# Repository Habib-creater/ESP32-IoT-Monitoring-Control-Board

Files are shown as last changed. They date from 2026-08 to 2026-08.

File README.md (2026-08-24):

# 4-Layer ESP32 IoT Monitoring and Control Board

<p align="center">
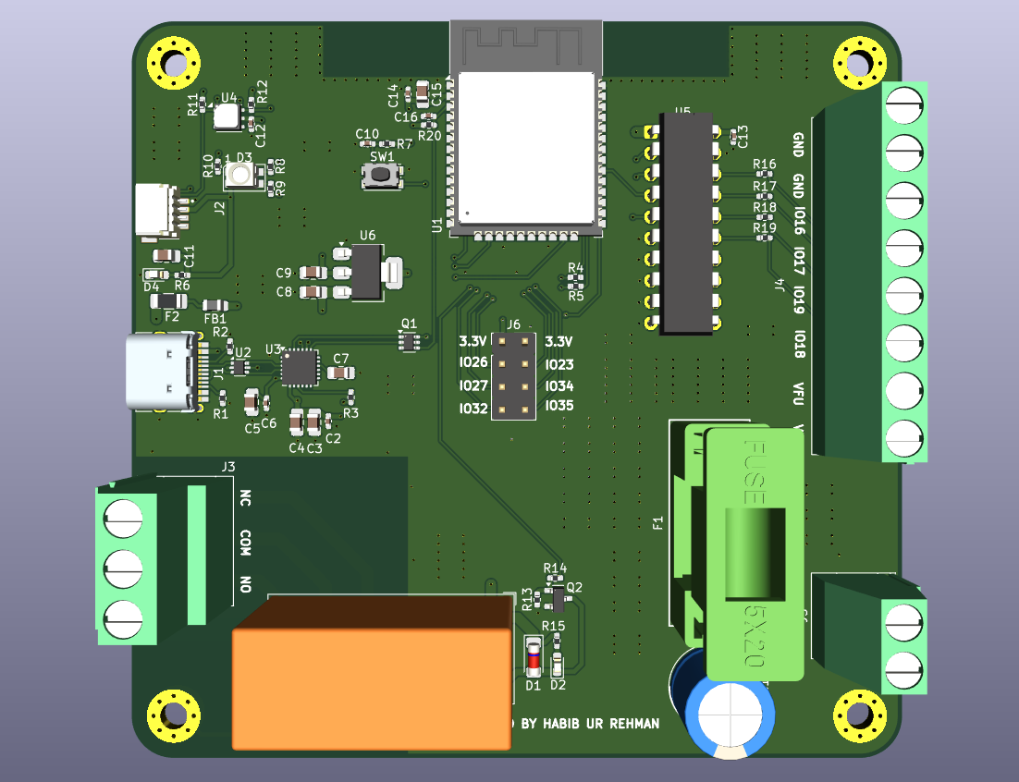
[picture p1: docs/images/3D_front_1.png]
4-Layer ESP32 IoT Monitoring and Control Board
  
</p>

<p align="center">
  <strong>ESP32-WROOM-32D • Si7021 • Relay • USB • Qwiic • 4-Layer PCB</strong>
</p>

<p align="center">
  A custom 4-layer ESP32-based hardware platform integrating environmental
  sensing, wired connectivity, relay control, USB programming, and
  expansion interfaces.
</p>

<p align="center">
  <a href="docs/IOT_Schematic.pdf">Schematic</a> •
  <a href="bom/IOT_BOM.csv">BOM</a> •
  <a href="manufacturing/gerbers/">Gerbers</a> •
  <a href="hardware/kicad/">KiCad Files</a>
</p>

---

## Overview

The **4-Layer ESP32 IoT Monitoring and Control Board** is a custom
embedded hardware platform built around the **ESP32-WROOM-32D** module.

The board combines environmental sensing through the **Si7021-A20**,
serial and wired interfaces, relay control, USB connectivity, Qwiic
expansion, and general-purpose GPIO in a compact 4-layer PCB design.

The complete hardware package is included in this repository, covering
the native **KiCad project**, electrical schematic, PCB layout, BOM,
Gerber and drill manufacturing files, pick-and-place data, and PCB
documentation.

> **Status:** Design files and manufacturing outputs included.

---

## Quick Access

| Resource | Description |
|---|---|
|  [Schematic PDF](docs/IOT_Schematic.pdf) | Complete electrical schematic |
|  [Bill of Materials](bom/IOT_BOM.csv) | Component BOM |
|  [Gerber & Drill Files](manufacturing/gerbers/) | PCB manufacturing outputs |
|  [KiCad Project](hardware/kicad/) | Native KiCad design files |
|  [PCB Images](docs/images/) | 3D renders and layer views |
|  [Pick-and-Place Data](manufacturing/pick-and-place/) | Component placement data |
|  [ERC / DRC Reports](docs/images/) | Design verification screenshots |

---

## Key Features

| Feature | Details |
|---|---|
| **Main Controller** | ESP32-WROOM-32D |
| **Environmental Sensor** | Si7021-A20 |
| **Sensor Interface** | I²C |
| **Serial / Expansion** | UART / GPIO |
| **Relay Control** | RT314A05 relay |
| **USB** | USB 2.0 Type-C interface |
| **Expansion** | Qwiic connector |
| **PCB** | 4-layer PCB |
| **EDA Software** | KiCad |
| **Manufacturing Data** | Gerber + PTH/NPTH drill files |
| **Assembly Data** | Top and bottom pick-and-place files |

---

## PCB Preview

### 3D Board Render

<p align="center">
  ESP32 IoT Board 3D Front Render
</p>

### Alternative 3D View

<p align="center">
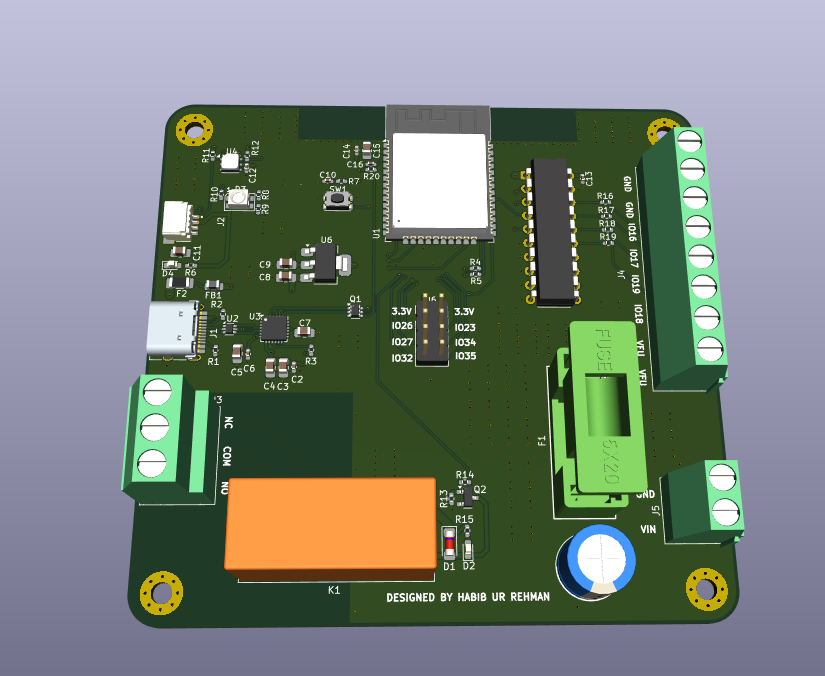
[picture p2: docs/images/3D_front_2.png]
ESP32 IoT Board Alternative 3D Render
  
</p>

### Bottom 3D View

<p align="center">
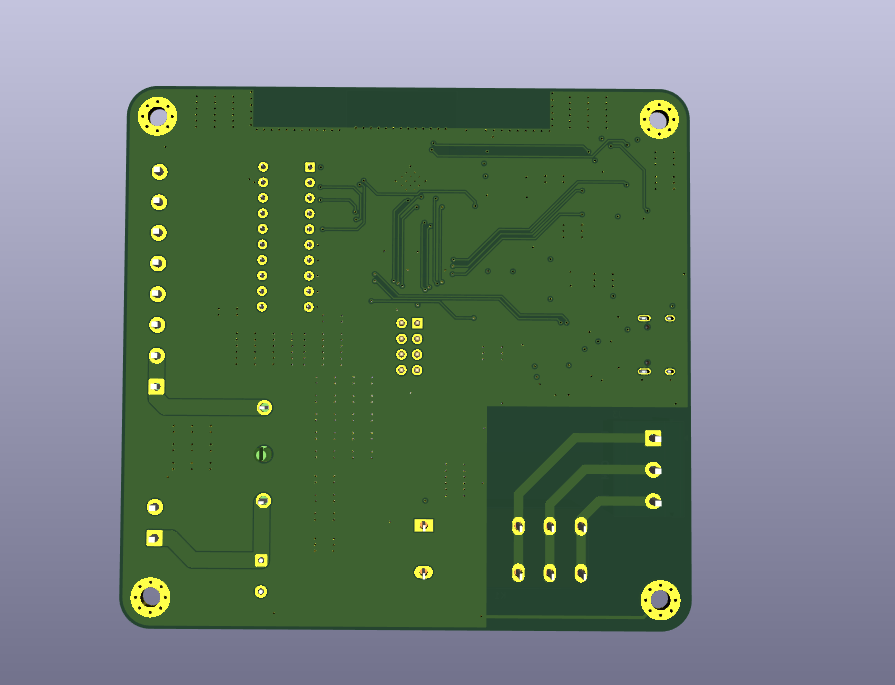
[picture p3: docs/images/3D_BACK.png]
ESP32 IoT Board Bottom 3D Render
  
</p>

---

## PCB Layer Views

### Front Copper / Layout

<p align="center">
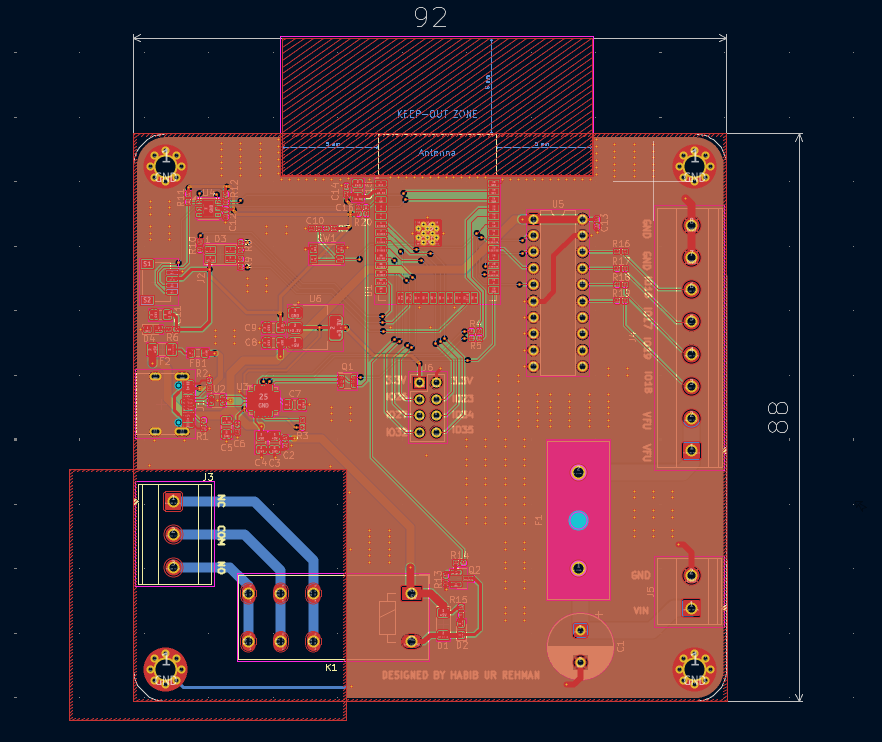
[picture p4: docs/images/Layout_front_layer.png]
ESP32 IoT PCB Front Layer
  
</p>

### Inner Layer 1

<p align="center">
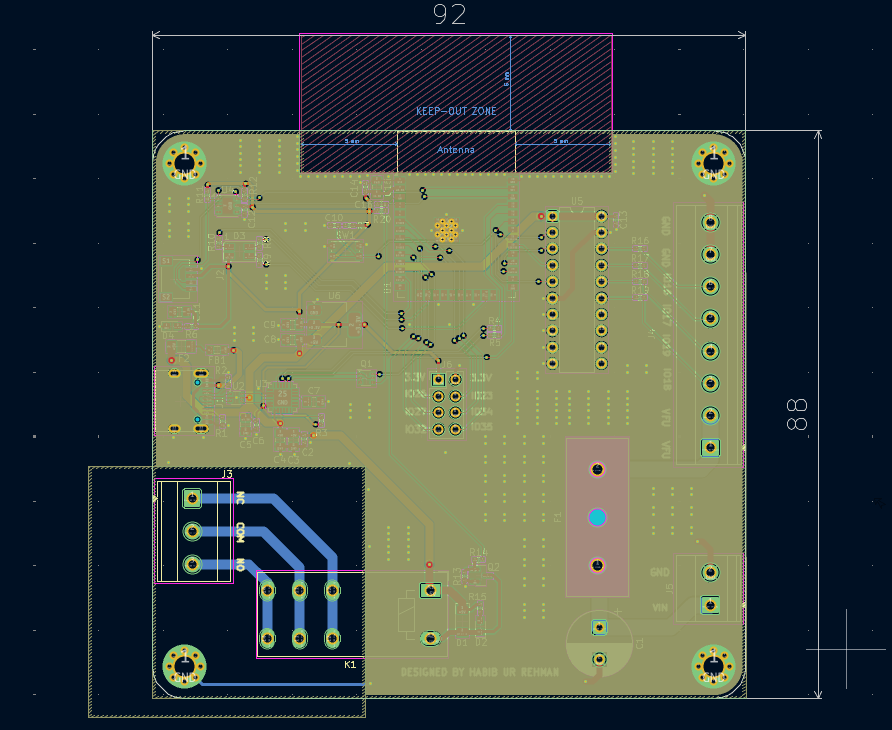
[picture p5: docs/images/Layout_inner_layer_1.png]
ESP32 IoT PCB Inner Layer 1
  
</p>

### Inner Layer 2

<p align="center">
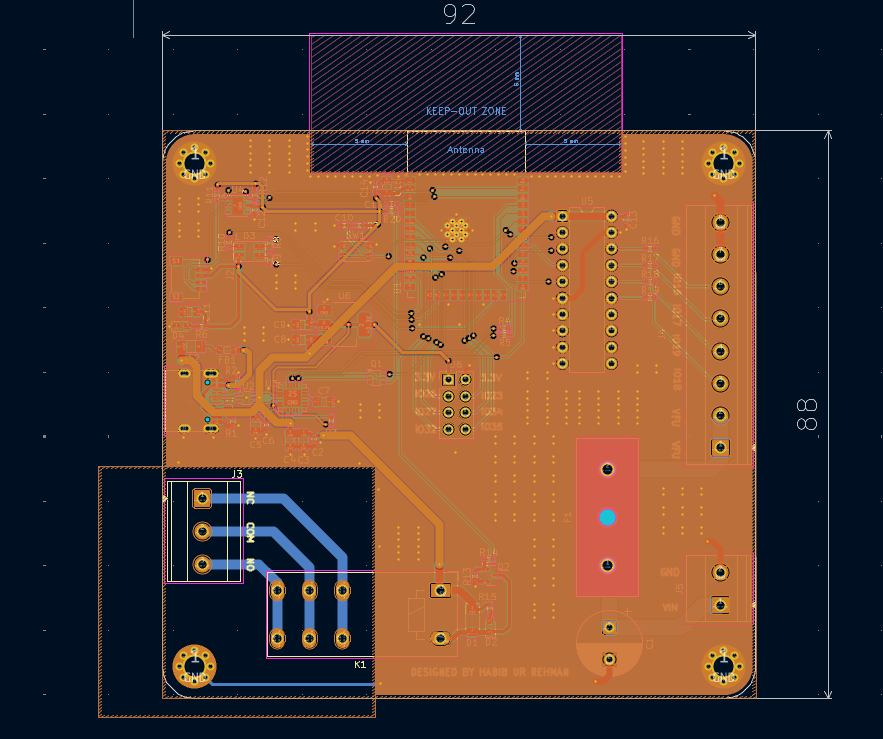
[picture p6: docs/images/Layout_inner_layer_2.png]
ESP32 IoT PCB Inner Layer 2
  
</p>

### Bottom Layer

<p align="center">
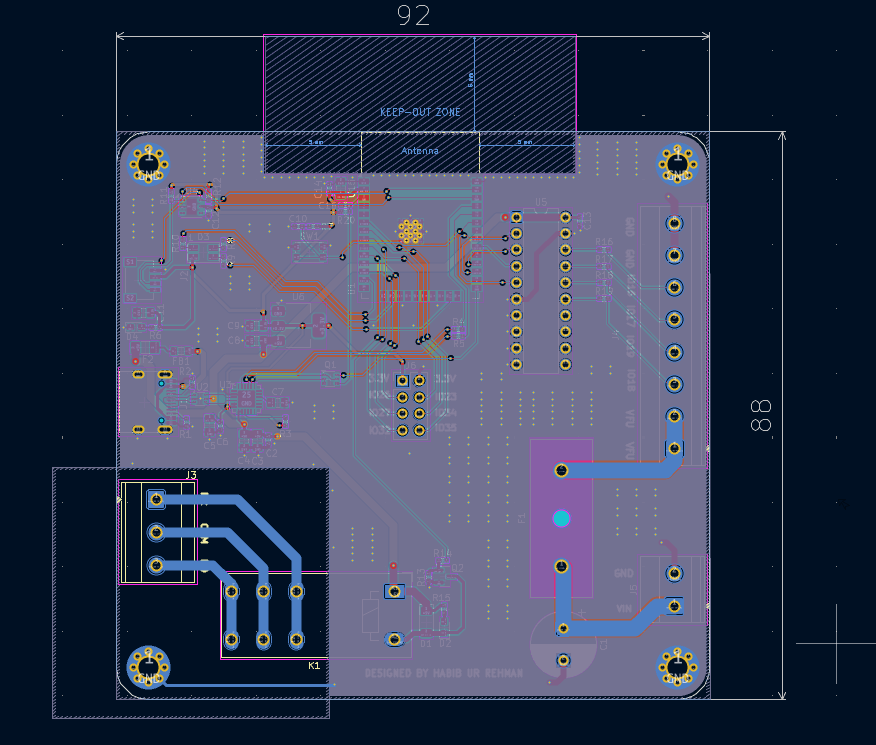
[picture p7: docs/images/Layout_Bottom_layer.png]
ESP32 IoT PCB Bottom Layer
  
</p>

---

## Hardware Architecture

The design brings together several functional blocks around the ESP32
controller.

### ESP32-WROOM-32D

The **ESP32-WROOM-32D** provides the primary processing and wireless
connectivity platform for the board.

### Environmental Sensing

The **Si7021-A20** provides digital environmental sensing through an
I²C interface.

### Relay Control

A **RT314A05 relay** provides a dedicated switched-output function with
associated transistor drive circuitry.

### USB and Programming

The board includes a **USB Type-C USB 2.0 interface** and associated
USB interface circuitry.

### Qwiic Expansion

A **Qwiic connector** provides an additional I²C expansion interface.

---

## PCB Design

The board is implemented as a **4-layer PCB** using **KiCad**.

### PCB Characteristics

- 4-layer PCB architecture
- ESP32-WROOM-32D module
- Environmental sensor interface
- Relay control circuitry
- USB Type-C interface
- Qwiic expansion
- Dedicated internal copper layers
- Compact component placement
- Through-hole and surface-mount components
- PTH and NPTH manufacturing data

---

## Design Files

The native KiCad project is located in:

[**hardware/kicad/**](hardware/kicad/)

### Main Files

| File | Description |
|---|---|
| `IOT.kicad_pro` | KiCad project |
| `IOT.kicad_sch` | Schematic source |
| `IOT.kicad_pcb` | PCB layout |

---

## Schematic

The exported electrical schematic is available as:

###  [View IOT Schematic PDF](docs/IOT_Schematic.pdf)

The schematic documents the ESP32 controller, environmental sensor,
USB interface, relay control, Qwiic interface,
power circuitry, and associated support components.

---

## Bill of Materials

The current component BOM is available here:

###  [View / Download IOT BOM](bom/IOT_BOM.csv)

The BOM contains the component references, quantities, values,
footprints, and associated component information from the design.

---

## Manufacturing Outputs

The generated manufacturing package is available under:

###  [Gerber & Drill Files](manufacturing/gerbers/)

The package contains:

- Front copper
- Back copper
- Inner copper layer 1
- Inner copper layer 2
- Front solder mask
- Back solder mask
- Front silkscreen
- Back silkscreen
- Front solder paste
- Back solder paste
- Board outline
- PTH drill data
- NPTH drill data
- Gerber job file

---

## Pick-and-Place Data

Assembly placement data is available in:

[**manufacturing/pick-and-place/**](manufacturing/pick-and-place/)

The repository contains separate top-side and bottom-side component
placement files.

---

## Design Verification

Design verification artifacts included with the project:

### ERC

<p align="center">
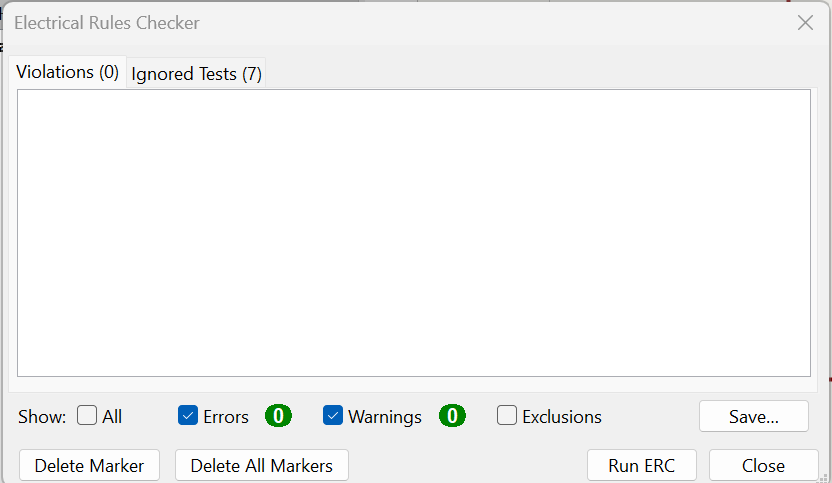
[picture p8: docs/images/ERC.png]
KiCad ERC Results
  
</p>

### DRC

<p align="center">
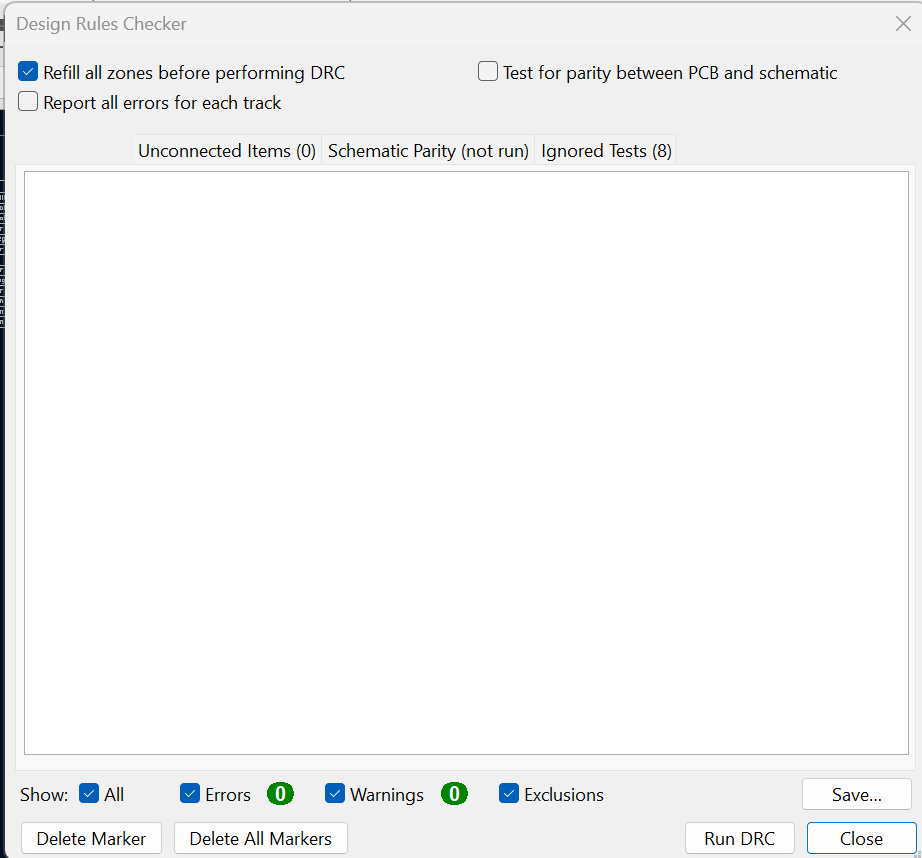
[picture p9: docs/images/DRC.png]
KiCad DRC Results
  
</p>

---

## Project Status

| Item | Status |
|---|---|
| Schematic | ✅ Completed |
| PCB Layout | ✅ Completed |
| PCB Layer Count | ✅ 4-layer |
| KiCad Project | ✅ Included |
| BOM | ✅ Included |
| Gerber Files | ✅ Generated |
| Drill Files | ✅ Generated |
| Pick-and-Place Data | ✅ Included |
| ERC Documentation | ✅ Included |
| DRC Documentation | ✅ Included |
| PCB Documentation | ✅ Included |

---

## Repository Structure

```text
.
├── hardware/
│   └── kicad/
│       ├── IOT.kicad_pro
│       ├── IOT.kicad_sch
│       └── IOT.kicad_pcb
│
├── manufacturing/
│   ├── gerbers/
│   │   ├── IOT-F_Cu.gbr
│   │   ├── IOT-In1_Cu.gbr
│   │   ├── IOT-In2_Cu.gbr
│   │   ├── IOT-B_Cu.gbr
│   │   ├── IOT-F_Mask.gbr
│   │   ├── IOT-B_Mask.gbr
│   │   ├── IOT-F_Silkscreen.gbr
│   │   ├── IOT-B_Silkscreen.gbr
│   │   ├── IOT-F_Paste.gbr
│   │   ├── IOT-B_Paste.gbr
│   │   ├── IOT-Edge_Cuts.gbr
│   │   ├── IOT-PTH.drl
│   │   ├── IOT-NPTH.drl
│   │   └── IOT-job.gbrjob
│   │
│   └── pick-and-place/
│       ├── IOT-top.pos
│       └── IOT-bottom.pos
│
├── bom/
│   └── IOT_BOM.csv
│
├── docs/
│   ├── images/
│   │   ├── 3D_front_1.png
│   │   ├── 3D_front_2.png
│   │   ├── 3D_BACK.png
│   │   ├── Layout_front_layer.png
│   │   ├── Layout_inner_layer_1.png
│   │   ├── Layout_inner_layer_2.png
│   │   ├── Layout_Bottom_layer.png
│   │   ├── ERC.png
│   │   └── DRC.png
│   │
│   └── IOT_Schematic.pdf
│
├── .gitignore
├── CONTRIBUTING.md
├── LICENSE
└── README.md
```

---

## Acknowledgements

This repository contains the hardware design package for the
4-Layer ESP32 IoT Monitoring and Control Board.

The repository includes the native KiCad source files together with
the associated schematic, PCB documentation, BOM, manufacturing
outputs, and assembly data.

---

## Contributing

Contributions, design reviews, and hardware improvements are welcome.

For proposed revisions, keep the native KiCad design files and
associated documentation aligned with the corresponding hardware
revision.

---

## License

The hardware design files in this repository are licensed under the
**CERN Open Hardware Licence Version 2 - Strongly Reciprocal
(CERN-OHL-S-2.0)**.

The CERN-OHL-S-2.0 licence is a hardware-specific open-source licence
for sharing, modifying, and distributing covered hardware designs.

**Copyright © 2026 Habib Ur Rehman**

See [`LICENSE`](LICENSE) for the licence information associated with
this repository.

---

## Author

### Habib Ur Rehman

**Electronics Engineering**

Embedded systems, PCB design, microcontrollers, electronics hardware,
and hardware development.

### Connect

- **GitHub:** [Habib-creater](https://github.com/Habib-creater)
- **LinkedIn:** [Habib Ur Rehman](https://www.linkedin.com/in/habib-ur-rehman-8321182b4/)

---

<p align="center">
  <strong>4-Layer ESP32 IoT Monitoring and Control Board</strong><br>
  Custom ESP32 Embedded Hardware Platform
</p>

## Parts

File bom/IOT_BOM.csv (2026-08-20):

Reference | Qty | Value | DNP | Exclude from BOM | Exclude from Board | Footprint | Description | Manufacturer | Manufacturer Part No | Supplier | Supplier Part No | Supplier Link
C1 | 1 | 1000uF/25V |  |  |  | Capacitor_THT:CP_Radial_D10.0mm_P5.00mm | CAP ALUM POLY 1000UF 20% 25V TH | KEMET | A750MV108M1EAAE014 | DigiKey | 399-A750MV108M1EAAE014-ND | https://www.digikey.com/en/products/detail/kemet/A750MV108M1EAAE014/13420146
C2,C6,C10,C12,C13,C14,C16 | 7 | 100n |  |  |  | Capacitor_SMD:C_0402_1005Metric_Pad0.74x0.62mm_HandSolder | CAP CER 100NF 10V X7R 0402 | Samsung Electro-Mechanics | CL05B104KP5VPNC | DigiKey | 1276-CL05B104KP5VPNCCT-ND | https://www.digikey.com/en/products/detail/samsung-electro-mechanics/CL05B104KP5VPNC/20498482
C3 | 1 | 4.7u |  |  |  | Capacitor_SMD:C_0805_2012Metric_Pad1.18x1.45mm_HandSolder | CAP CER 4.7UF 16V X5R 0805 | Samsung Electro-Mechanics | CL21A475KOFNNNE | DigiKey | 1276-1065-1-ND | https://www.digikey.com/en/products/detail/tdk/C1005X5R1A475K050BC/3951056 | https://www.digikey.com/en/products/detail/samsung-electro-mechanics/CL21A475KOFNNNE/3886723
C4,C5,C8,C9,C11,C15 | 6 | 22u |  |  |  | Capacitor_SMD:C_0805_2012Metric_Pad1.18x1.45mm_HandSolder | CAP CER 22UF 16V X5R 0805 | Samsung Electro-Mechanics | CL21A226KOQNNNE | DigiKey | 1276-6526-1-ND | https://www.digikey.com/en/products/detail/samsung-electro-mechanics/CL21A226KOQNNNE/5961010
C7 | 1 | 4.7u | DNP | Excluded from BOM |  | Capacitor_SMD:C_0805_2012Metric_Pad1.18x1.45mm_HandSolder | CAP CER 4.7UF 16V X5R 0805 | Samsung Electro-Mechanics | CL21A475KOFNNNE | DigiKey | 1276-1065-1-ND | https://www.digikey.com/en/products/detail/samsung-electro-mechanics/CL21A475KOFNNNE/3886723
D1 | 1 | LL4148 |  |  |  | Diode_SMD:D_MiniMELF | SWITCHING DIODE 0.3A 100V SOD-80 | Lumimax Optoelectronic Technology | LL4148 | DigiKey | 4491-LL4148TR-ND | https://www.digikey.com/en/products/detail/lumimax-optoelectronic-technology/LL4148/24769314
D2 | 1 | YELLOW |  |  |  | LED_SMD:LED_0603_1608Metric_Pad1.05x0.95mm_HandSolder | LED YELLOW 0603 SMD | Vishay Semiconductor Opto Division | TLMY1100-GS15 | DigiKey | 751-TLMY1100-GS15CT-ND | https://www.digikey.com/en/products/detail/vishay-semiconductor-opto-division/TLMY1100-GS15/16652844
D3 | 1 | LED_RGBA |  |  |  | LED_SMD:LED_RGB_Wuerth-PLCC4_3.2x2.8mm_150141M173100 | LED RGB CLEAR 3528 SMD | Würth Elektronik | 150141M173100 | DigiKey | 732-4998-1-ND | https://www.digikey.com/en/products/detail/w%C3%BCrth-elektronik/150141M173100/4489960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
D4 | 1 | LED |  |  |  | LED_SMD:LED_0603_1608Metric_Pad1.05x0.95mm_HandSolder | LED RED 0603 SMD | Vishay Semiconductor Opto Division | VLMS1300-GS08 | DigiKey | VLMS1300-GS08CT-ND | https://www.digikey.com/en/products/detail/vishay-semiconductor-opto-division/VLMS1300-GS08/2813354
F1 | 1 | Fuse |  |  |  | Fuse_1:696105003002 | FUSEHOLDER BLOCKS - PCB - CLIP C | Würth Elektronik | 6.96E+11 | DigiKey | 732-11373-ND | https://www.digikey.com/en/products/detail/w%C3%BCrth-elektronik/696105003002/7244557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
F2 | 1 | Polyfuse1A |  |  |  | Fuse:Fuse_1206_3216Metric_Pad1.42x1.75mm_HandSolder | Polymeric PTC Resettable Fuse 8V 1.1 A Ih Surface Mount 1206 (3216 Metric), Concave | Littelfuse Inc. | 1206L110THYR | DigiKey | F3371CT-ND | https://www.digikey.com/en/products/detail/littelfuse-inc/1206L110THYR/2090976
FB1 | 1 | BLM21PG221 |  |  |  | Inductor_SMD:L_0805_2012Metric | FERRITE BEAD 220 OHM 0805 1LN | Murata Electronics | BLM21PG221SN1D | DigiKey | 490-1054-1-ND | https://www.digikey.com/en/products/detail/murata-electronics/BLM21PG221SN1D/364909
H1,H2,H3,H4 | 4 | MountingHole_Pad |  | Excluded from BOM |  | MountingHole:MountingHole_3.2mm_M3_Pad_Via | Mounting Hole with connection
J1 | 1 | USB_C_Receptacle_USB2.0_16P |  |  |  | Connector_USB:USB_C_Receptacle_HRO_TYPE-C-31-M-12 | CONN RCPT Type-C 16POS SMD | Korean Hroparts Elec | TYPE-C-31-M-12 | LCSC | C165948 | https://www.lcsc.com/product-detail/USB-Type-C_Korean-Hroparts-Elec-TYPE-C-31-M-12_C165948.html
J2 | 1 | Conn_01x04 |  |  |  | QWIIC CONNECTOR 4P:SPARKFUN_PRT-14417 | QWIIC CONNECTOR SMD 4-PIN | SparkFun Electronics | 14417 | DigiKey | 1568-14417-ND | https://www.digikey.com/en/products/detail/sparkfun-electronics/14417/7652746
J3 | 1 | Screw_Terminal_01x03 |  |  |  | TerminalBlock_Phoenix:TerminalBlock_Phoenix_MKDS-3-3-5.08_1x03_P5.08mm_Horizontal | TERM BLK 3P SIDE ENT 5.08MM PCB | Phoenix Contact | 1729131 | DigiKey | 277-1248-ND | https://www.digikey.com/en/products/detail/phoenix-contact/1729131/260616
J4 | 1 | Screw_Terminal_01x08 |  |  |  | TerminalBlock_Phoenix:TerminalBlock_Phoenix_MKDS-1,5-8_1x08_P5.00mm_Horizontal | TERM BLK 8POS SIDE ENTRY 5MM PCB | Phoenix Contact | 1711084 | DigiKey | 277-1025-ND | https://www.digikey.com/en/products/detail/phoenix-contact/1711084/260393
J5 | 1 | Screw_Terminal_01x02 |  |  |  | TerminalBlock_Phoenix:TerminalBlock_Phoenix_MKDS-1,5-2_1x02_P5.00mm_Horizontal | TERM BLK 2POS SIDE ENTRY 5MM PCB | Phoenix Contact | 1715022 | DigiKey | 277-1258-ND | https://www.digikey.com/en/products/detail/phoenix-contact/1715022/260626
J6 | 1 | Conn_02x04_Odd_Even |  |  |  | Connector_PinHeader_2.54mm:PinHeader_2x04_P2.54mm_Vertical | CONN HEADER VERT 8POS 2.54MM | Samtec Inc. | TD-104-T-A | DigiKey | 612-TD-104-T-A-ND | https://www.digikey.com/en/products/detail/samtec-inc/TD-104-T-A/1105554
K1 | 1 | RT314A05 |  |  |  | Relay_THT:Relay_SPDT_Schrack-RT1-16A-FormC_RM5mm | Schrack RT1 relay, bistable single pole dual throw, single DC coil, 5V | TE Connectivity Potter & Brumfield Relays | RT314A05 | DigiKey | PB1695-ND | https://www.digikey.com/en/products/detail/te-connectivity-potter-brumfield-relays/RT314A05/1427660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
Q1 | 1 | UMH3N |  |  |  | Package_TO_SOT_SMD:SOT-363_SC-70-6 | TRANS PREBIAS 2NPN 50V UMT6 | Rohm Semiconductor | UMH3NFHATN | DigiKey | UMH3NFHATNCT-ND | https://www.digikey.com/en/products/detail/rohm-semiconductor/UMH3NFHATN/8028268
Q2 | 1 | BC817 |  |  |  | Package_TO_SOT_SMD:SOT-23 | Bipolar (BJT) Transistor NPN 45 V 800 mA 100MHz 310 mW Surface Mount SOT-23 | MCC (Micro Commercial Components) | BC817-40-TP | DigiKey | BC817-40-TPMSCT-ND | https://www.digikey.com/en/products/detail/mcc-micro-commercial-components/BC817-40-TP/1959413
R1,R2 | 2 | 5k1 |  |  |  | Resistor_SMD:R_0402_1005Metric_Pad0.72x0.64mm_HandSolder | RES 5.1K OHM 1% 1/16W 0402 | YAGEO | RC0402FR-075K1L | DigiKey | 311-5.10KLRCT-ND | https://www.digikey.com/en/products/detail/yageo/RC0402FR-075K1L/726624
R3 | 1 | 10k |  |  |  | Resistor_SMD:R_0402_1005Metric_Pad0.72x0.64mm_HandSolder | RES 10K OHM 1% 1/16W 0402 | YAGEO | RC0402FR-0710KL | DigiKey | 311-10.0KLRCT-ND | https://www.digikey.com/en/products/detail/yageo/RC0402FR-0710KL/726523
R4,R5,R16,R17,R18,R19 | 6 | 22R |  |  |  | Resistor_SMD:R_0402_1005Metric_Pad0.72x0.64mm_HandSolder | RES 22 OHM 1% 1/16W 0402 | YAGEO | RC0402FR-0722RL | DigiKey | 311-22.0LRCT-ND | https://www.digikey.com/en/products/detail/yageo/RC0402FR-0722RL/726562
R6,R8,R9,R10,R14,R15 | 6 | 1K |  |  |  | Resistor_SMD:R_0402_1005Metric_Pad0.72x0.64mm_HandSolder | RES 1K OHM 1% 1/16W 0402 | YAGEO | RC0402FR-071KL | DigiKey | 311-1.00KLRCT-ND | https://www.digikey.com/en/products/detail/yageo/RC0402FR-071KL/726513
R7,R13,R20 | 3 | 10K |  |  |  | Resistor_SMD:R_0402_1005Metric_Pad0.72x0.64mm_HandSolder | RES 10K OHM 1% 1/16W 0402 | YAGEO | RC0402FR-0710KL | DigiKey | 311-10.0KLRCT-ND | https://www.digikey.com/en/products/detail/yageo/RC0402FR-0710KL/726523
R11,R12 | 2 | 4K7 |  |  |  | Resistor_SMD:R_0402_1005Metric_Pad0.72x0.64mm_HandSolder | RES 4.7K OHM 1% 1/16W 0402 | YAGEO | RC0402FR-074K7L | DigiKey | 311-4.7KLRCT-ND | https://www.digikey.com/en/products/detail/yageo/RC0402FR-074K7L/2827563
SW1 | 1 | SW_SPST |  |  |  | Button_Switch_SMD:SW_Push_1P1T_NO_CK_KMR2 | SWITCH TACTILE SPST-NO 0.05A 32V | C&K | KMR211G LFS | DigiKey | 108-KMR211GLFSCT-ND | https://www.digikey.com/en/products/detail/c-k/KMR211G-LFS/550475
U1 | 1 | ESP32-WROOM-32D |  |  |  | RF_Module:ESP32-WROOM-32D | RF Module, ESP32-D0WD SoC, Wi-Fi 802.11b/g/n, Bluetooth, BLE, 32-bit, 2.7-3.6V, onboard antenna, SMD | ESPRESSIF | ESP32-WROOM-32D-N4 | LCSC | C473012 | https://www.lcsc.com/product-detail/C473012.html?s_z=n_q_ESP32-WROOM-32D
U2 | 1 | USBLC6-2P6 |  |  |  | Package_TO_SOT_SMD:SOT-666 | TVS DIODE 5.25VWM 17VC SOT666 | STMicroelectronics | USBLC6-2P6 | DigiKey | 497-5026-1-ND | https://www.digikey.com/en/products/detail/stmicroelectronics/USBLC6-2P6/1007440
U3 | 1 | CP2104 |  |  |  | Package_DFN_QFN:QFN-24-1EP_4x4mm_P0.5mm_EP2.6x2.6mm | IC SGL USB-TO-UART BRIDGE 24QFN | Silicon Labs | CP2104-F03-GMR | DigiKey | 336-4146-1-ND | https://www.digikey.com/en/products/detail/silicon-labs/CP2104-F03-GMR/4069045
U4 | 1 | Si7021-A20 |  |  |  | Package_DFN_QFN:DFN-6-1EP_3x3mm_P1mm_EP1.5x2.4mm | SENS HUMID/TEMP 3.6V I2C 3% 6DFN | Silicon Labs | SI7021-A20-IMR | DigiKey | 336-5200-1-ND | https://www.digikey.com/en/products/detail/silicon-labs/SI7021-A20-IMR/5048940
U5 | 1 | 74HC245 |  |  |  | Package_DIP:DIP-20_W7.62mm | IC TXRX 2V/6V 20-PDIP | Texas Instruments | CD74HC245E | DigiKey | 296-12800-5-ND | https://www.digikey.com/en/products/detail/texas-instruments/CD74HC245E/475927
U6 | 1 | TLV1117LV-3.3 |  |  |  | Package_TO_SOT_SMD:SOT-223-3_TabPin2 | 3.3V Positive Fixed SOT-223-3 Voltage Regulators - Linear, Low Drop Out (LDO) Regulators | TECH PUBLIC | TPTLV1117LV33DCYR | LCSC | C52146079 | https://www.lcsc.com/product-detail/C52146079.html?s_z=n_q_l_TLV1117LV-3.3

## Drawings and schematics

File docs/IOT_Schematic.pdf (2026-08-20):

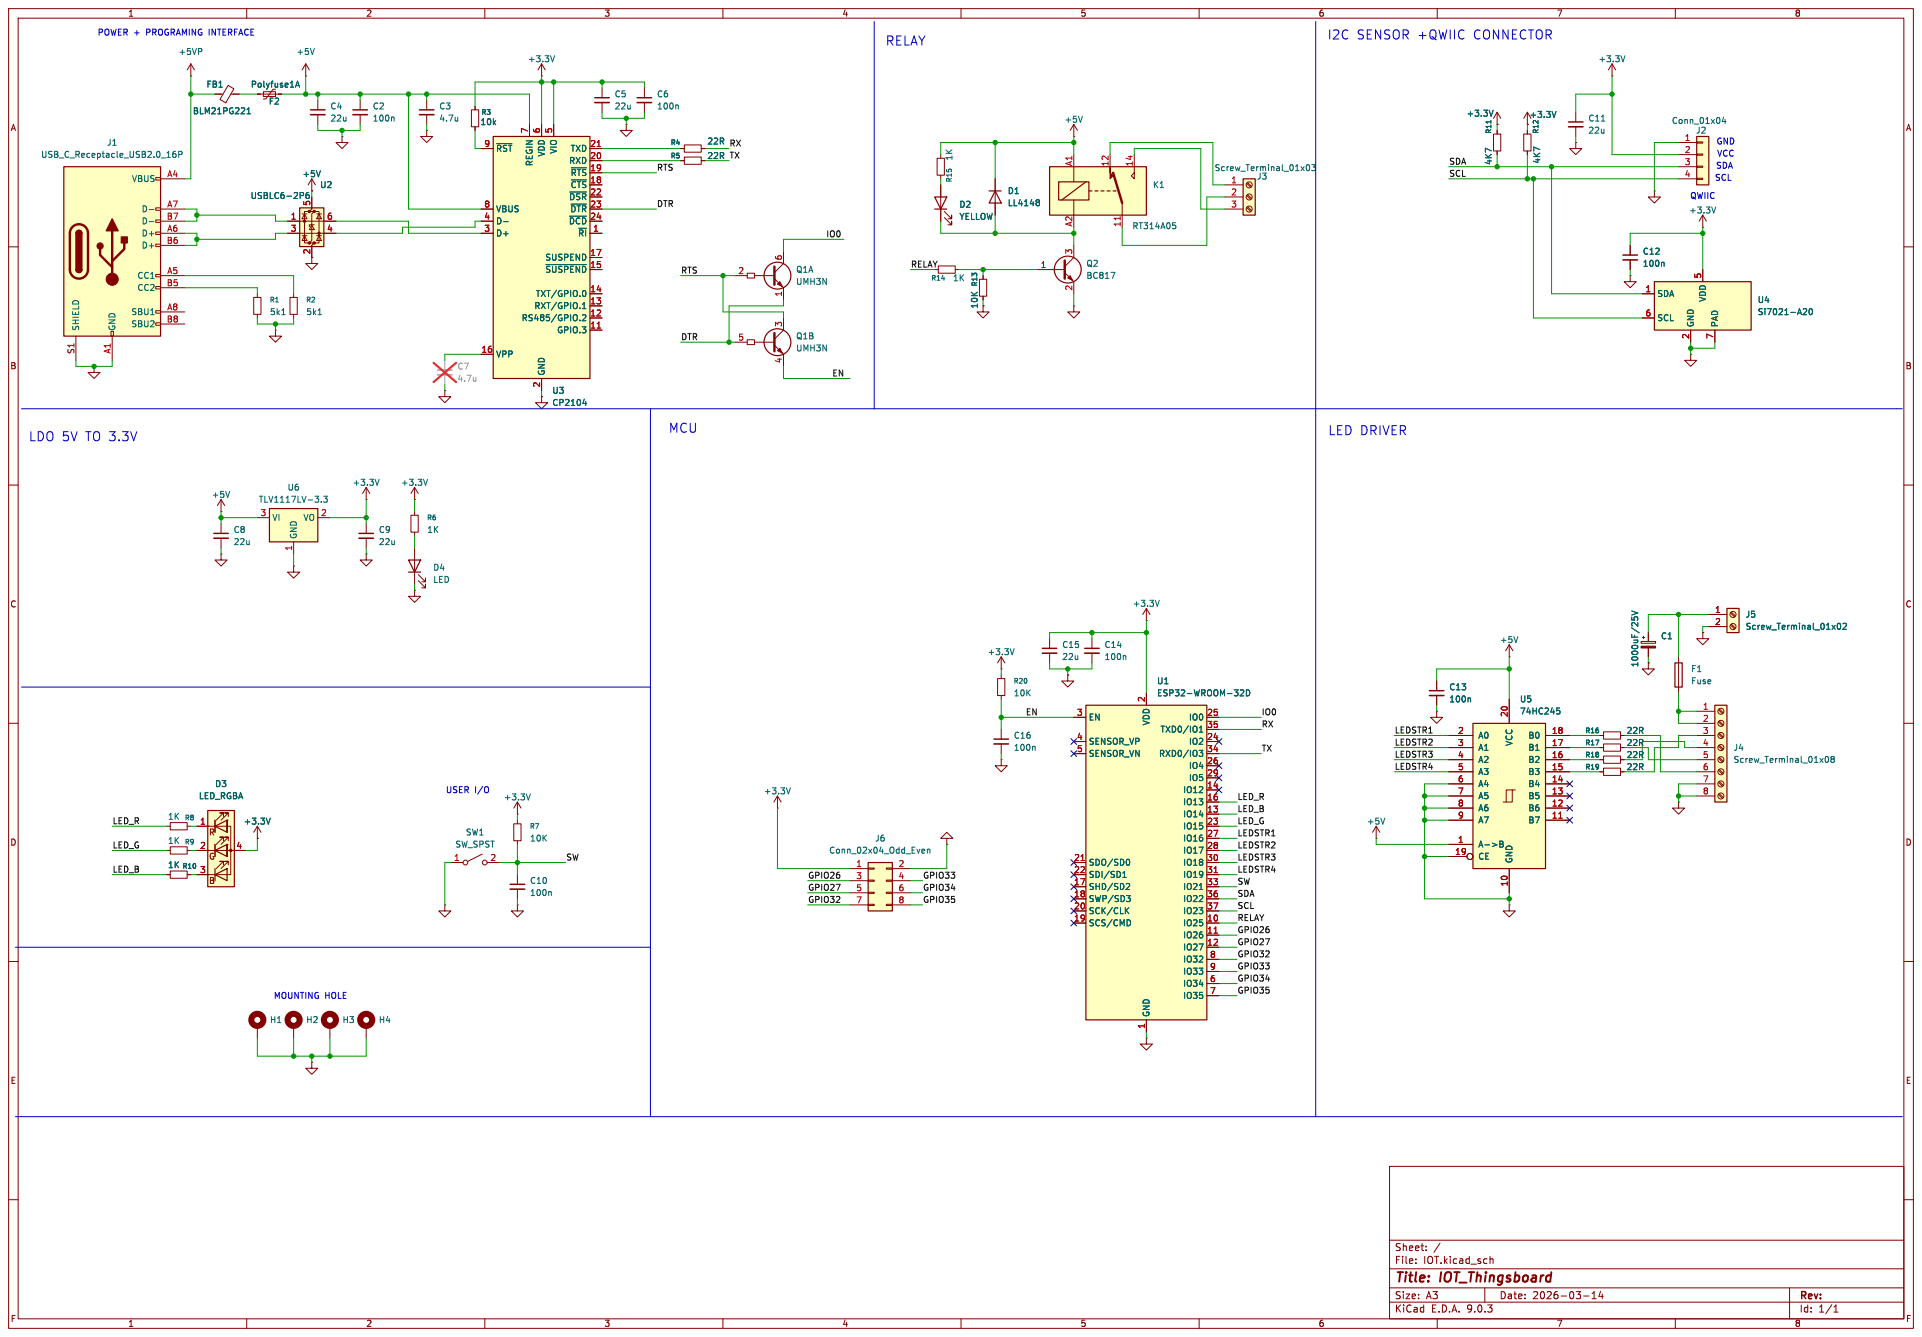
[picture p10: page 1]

I2C SENSOR +QWIIC CONNECTOR RELAY

5 TXD 21 RXD 20 ~{RTS} 19 ~{CTS} 18 ~{DSR} 22 ~{DTR} 23 ~{DCD} 24 ~{RI}1 SUSPEND 17 ~{SUSPEND}15 TXT/GPIO.0 14 RXT/GPIO.1 13 RS485/GPIO.2 12 GPIO.3 11 U3 CP2104 C7

5 TXD 21 RXD 20 ~{RTS} 19 ~{CTS} 18 ~{DSR} 22 ~{DTR} 23 ~{DCD} 24 ~{RI}1 SUSPEND 17 ~{SUSPEND}15 TXT/GPIO.0 14 RXT/GPIO.1 13 RS485/GPIO.2 12 GPIO.3 11 R4 22R

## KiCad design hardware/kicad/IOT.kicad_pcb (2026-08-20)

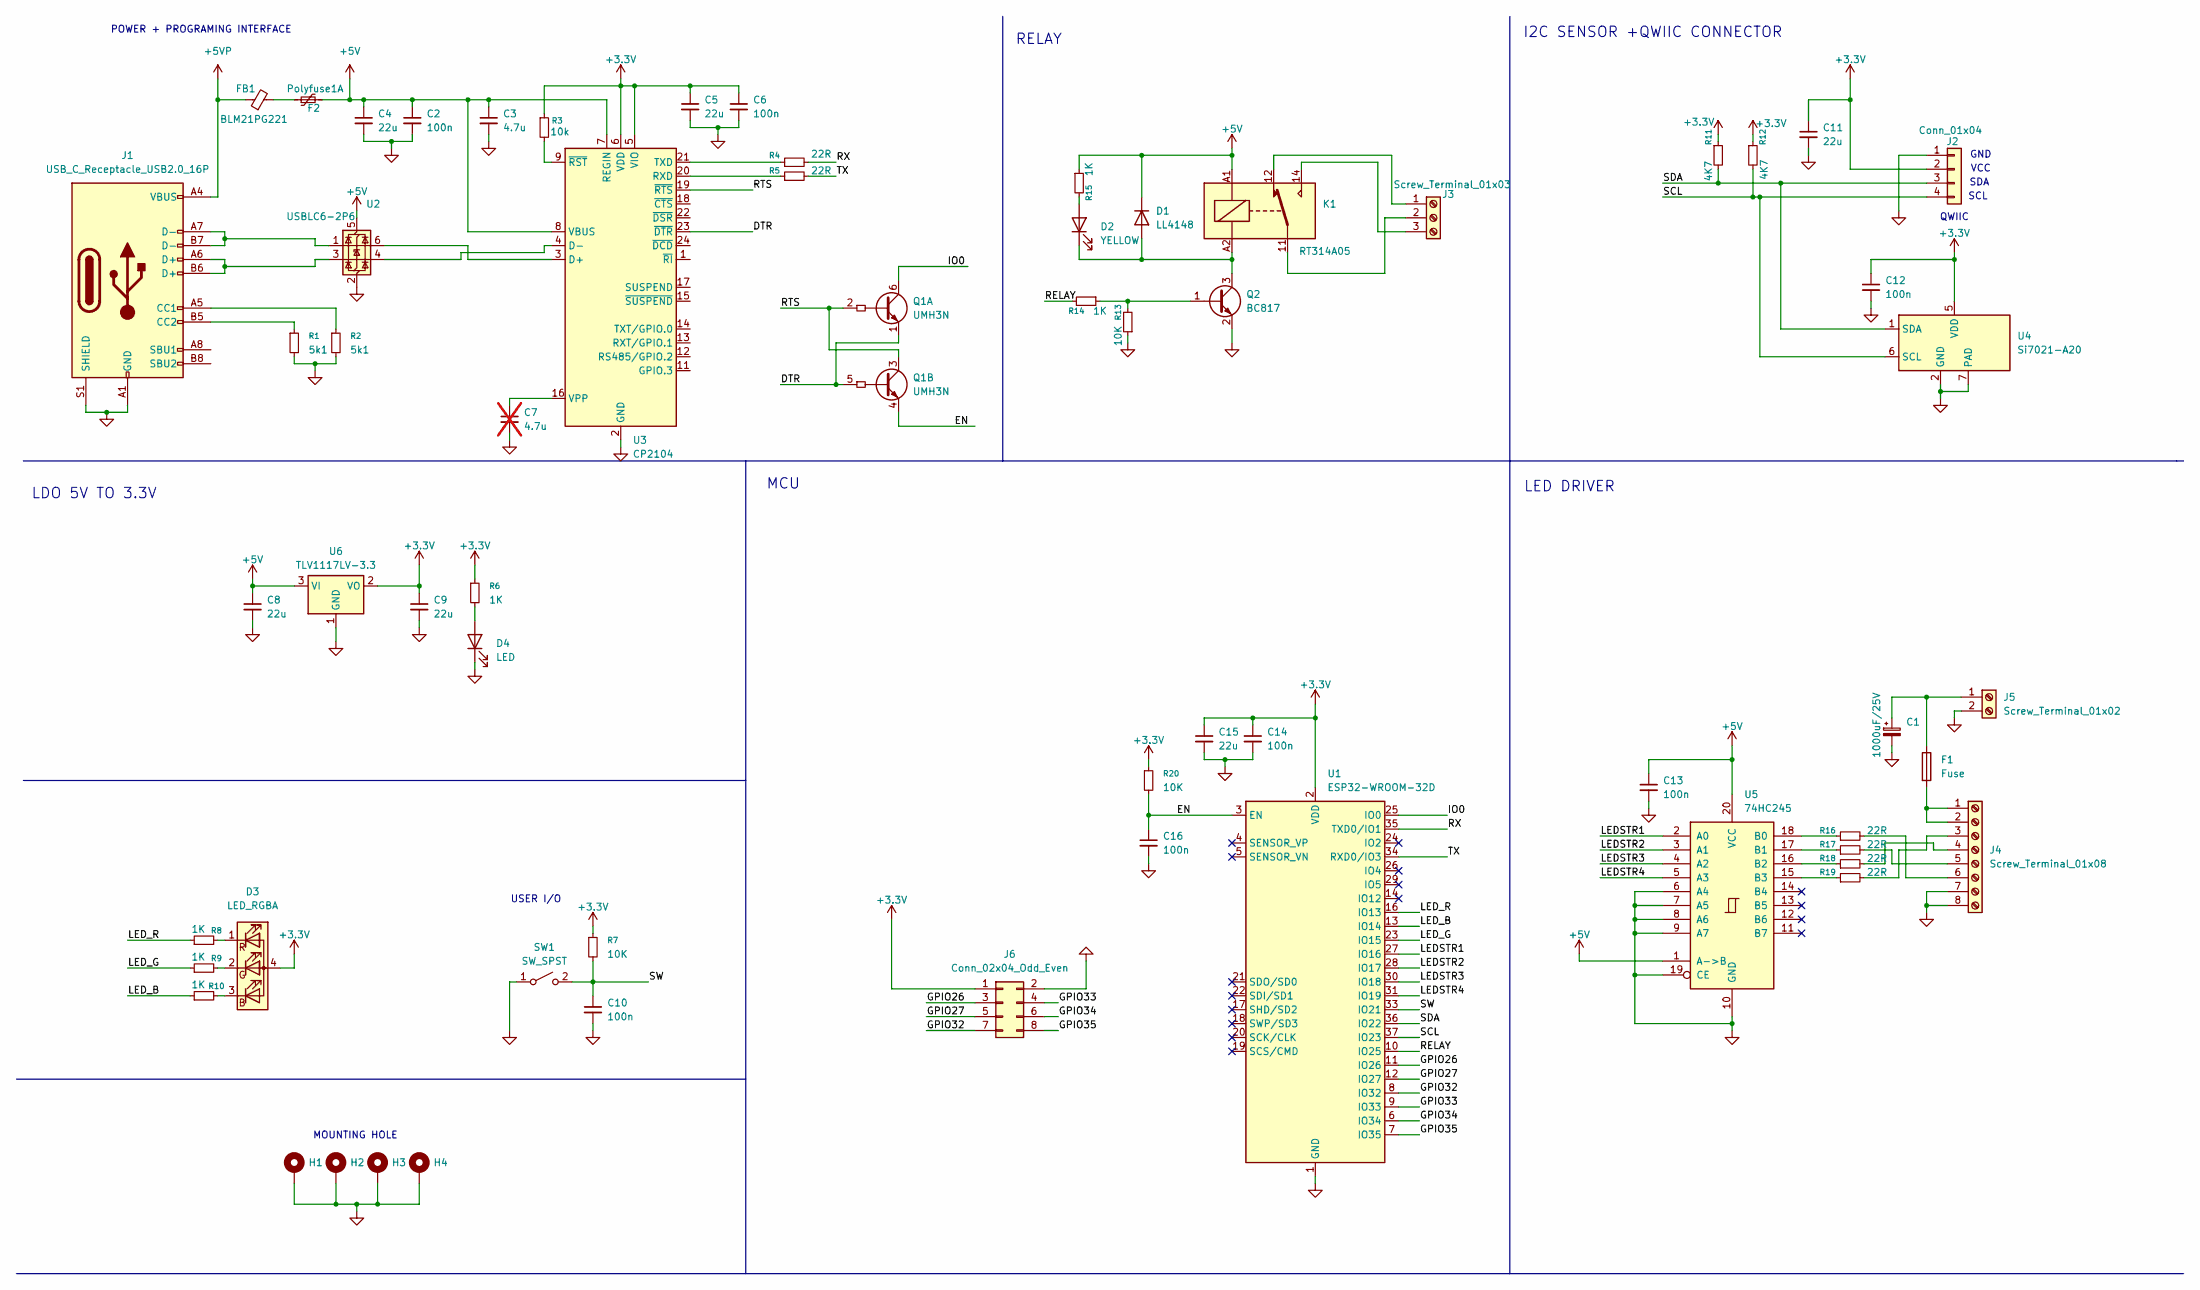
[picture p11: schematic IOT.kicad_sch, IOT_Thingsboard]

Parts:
C1: 1000uF/25V; CP_Radial_D10.0mm_P5.00mm
C2, C6, C10, C12, C13, C14, C16: 100n; C_0402_1005Metric_Pad0.74x0.62mm_HandSolder
C3: 4.7u; C_0805_2012Metric_Pad1.18x1.45mm_HandSolder
C4, C5, C8, C9, C11, C15: 22u; C_0805_2012Metric_Pad1.18x1.45mm_HandSolder
C7: 4.7u; C_0805_2012Metric_Pad1.18x1.45mm_HandSolder; not fitted
D1: LL4148; D_MiniMELF
D2: YELLOW; LED_0603_1608Metric_Pad1.05x0.95mm_HandSolder
D3: LED_RGBA; LED_RGB_Wuerth-PLCC4_3.2x2.8mm_150141M173100
D4: LED; LED_0603_1608Metric_Pad1.05x0.95mm_HandSolder
F1: Fuse; 696105003002
F2: Polyfuse1A; Fuse_1206_3216Metric_Pad1.42x1.75mm_HandSolder
FB1: BLM21PG221; L_0805_2012Metric
H1, H2, H3, H4: MountingHole_Pad; MountingHole_3.2mm_M3_Pad_Via
J1: USB_C_Receptacle_USB2.0_16P; USB_C_Receptacle_HRO_TYPE-C-31-M-12
J2: Conn_01x04; SPARKFUN_PRT-14417
J3: Screw_Terminal_01x03; TerminalBlock_Phoenix_MKDS-3-3-5.08_1x03_P5.08mm_Horizontal
J4: Screw_Terminal_01x08; TerminalBlock_Phoenix_MKDS-1,5-8_1x08_P5.00mm_Horizontal
J5: Screw_Terminal_01x02; TerminalBlock_Phoenix_MKDS-1,5-2_1x02_P5.00mm_Horizontal
J6: Conn_02x04_Odd_Even; PinHeader_2x04_P2.54mm_Vertical
K1: RT314A05; Relay_SPDT_Schrack-RT1-16A-FormC_RM5mm
Q1: UMH3N; SOT-363_SC-70-6
Q2: BC817; SOT-23
R1, R2: 5k1; R_0402_1005Metric_Pad0.72x0.64mm_HandSolder
R3: 10k; R_0402_1005Metric_Pad0.72x0.64mm_HandSolder
R4, R5, R16, R17, R18, R19: 22R; R_0402_1005Metric_Pad0.72x0.64mm_HandSolder
R6, R8, R9, R10, R14, R15: 1K; R_0402_1005Metric_Pad0.72x0.64mm_HandSolder
R7, R13, R20: 10K; R_0402_1005Metric_Pad0.72x0.64mm_HandSolder
R11, R12: 4K7; R_0402_1005Metric_Pad0.72x0.64mm_HandSolder
SW1: SW_SPST; SW_Push_1P1T_NO_CK_KMR2
U1: ESP32-WROOM-32D
U2: USBLC6-2P6; SOT-666
U3: CP2104; QFN-24-1EP_4x4mm_P0.5mm_EP2.6x2.6mm
U4: Si7021-A20; DFN-6-1EP_3x3mm_P1mm_EP1.5x2.4mm
U5: 74HC245; DIP-20_W7.62mm
U6: TLV1117LV-3.3; SOT-223-3_TabPin2

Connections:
+3.3V: C5.1, C6.1, C9.1, C11.1, C12.1, C14.1, C15.1, D3.4 (A), J2.2, J6.1, R3.1, R6.1, R7.1, R11.1, R12.1, R20.1, U1.2 (VDD), U3.5 (VIO), U3.6 (VDD), U4.5 (VDD), U6.2 (VO); also elsewhere on the board
+5V: C2.1, C3.1, C4.1, C8.1, C13.1, D1.1 (K), F2.2, K1.A1, R15.1, U2.5 (VBUS), U3.7 (REGIN), U3.8 (VBUS), U5.1 (A->B), U5.20 (VCC), U6.3 (VI)
+5VP: FB1.1, J1.A4 (VBUS), J1.A9 (VBUS), J1.B4 (VBUS), J1.B9 (VBUS)
/DTR: Q1.1 (E1), Q1.5 (B2), U3.23 (~DTR)
/EN: C16.1, Q1.4 (E2), R20.2, U1.3 (EN)
/GPIO26: J6.3, U1.11 (IO26); also elsewhere on the board
/GPIO27: J6.5, U1.12 (IO27); also elsewhere on the board
/GPIO32: J6.7, U1.8 (IO32); also elsewhere on the board
/GPIO33: J6.4, U1.9 (IO33); also elsewhere on the board
/GPIO34: J6.6, U1.6 (IO34); also elsewhere on the board
/GPIO35: J6.8, U1.7 (IO35); also elsewhere on the board
/IO0: Q1.6 (C1), U1.25 (IO0)
/LEDSTR1: U1.27 (IO16), U5.2 (A0)
/LEDSTR2: U1.28 (IO17), U5.3 (A1)
/LEDSTR3: U1.30 (IO18), U5.4 (A2)
/LEDSTR4: U1.31 (IO19), U5.5 (A3)
/LED_B: R10.1, U1.13 (IO14)
/LED_G: R9.1, U1.23 (IO15)
/LED_R: R8.1, U1.16 (IO13)
/RELAY: R14.2, U1.10 (IO25)
/RTS: Q1.2 (B1), Q1.3 (C2), U3.19 (~RTS)
/RX: R4.2, U1.35 (TXD0/IO1)
/SCL: J2.4, R12.2, U1.37 (IO23), U4.6 (SCL)
/SDA: J2.3, R11.2, U1.36 (IO22), U4.1 (SDA)
/SW: C10.1, R7.2, SW1.2 (B), U1.33 (IO21)
/TX: R5.2, U1.34 (RXD0/IO3)
GND: C1.2, C2.2, C3.2, C4.2, C5.2, C6.2, C7.2, C8.2, C9.2, C10.2, C11.2, C12.2, C13.2, C14.2, C15.2, C16.2, D4.1 (K), H1.1, H2.1, H3.1, H4.1, J1.A1 (GND), J1.A12 (GND), J1.B1 (GND), J1.B12 (GND), J1.S1 (SHIELD), J2.1, J4.7, J4.8, J5.2, J6.2, Q2.2 (E), R1.2, R2.2, R13.1, SW1.1 (A), U1.1 (GND), U1.15 (GND), U1.38 (GND), U1.39 (GND), U2.2 (GND), U3.2 (GND), U3.25 (GND), U4.2 (GND), U4.7 (PAD), U5.6 (A4), U5.7 (A5), U5.8 (A6), U5.9 (A7), U5.10 (GND), U5.19 (CE), U6.1 (GND); also elsewhere on the board
unnamed: D1.2 (A), D2.1 (K), K1.A2, Q2.3 (C)
unnamed: D2.2 (A), R15.2
unnamed: D3.3 (BK), R10.2
unnamed: D3.2 (GK), R9.2
unnamed: D3.1 (RK), R8.2
unnamed: D4.2 (A), R6.2
unnamed: F2.1, FB1.2
unnamed: J1.A5 (CC1), R2.1
unnamed: J1.B5 (CC2), R1.1
unnamed: J1.A6 (D+), J1.B6 (D+), U2.3 (I/O2)
unnamed: J1.A7 (D-), J1.B7 (D-), U2.1 (I/O1)
unnamed: J3.1, K1.12
unnamed: J3.2, K1.11
unnamed: J3.3, K1.14
unnamed: F1.2, J4.1, J4.2
unnamed: J4.3, R19.2
unnamed: J4.4, R18.2
unnamed: J4.5, R17.2
unnamed: J4.6, R16.2
unnamed: C1.1, F1.1, J5.1
unnamed: Q2.1 (B), R13.2, R14.1
unnamed: U2.6 (I/O1), U3.3 (D+)
unnamed: U2.4 (I/O2), U3.4 (D-)
unnamed: R5.1, U3.20 (RXD)
unnamed: R4.1, U3.21 (TXD)
unnamed: C7.1, U3.16 (VPP)
unnamed: R3.2, U3.9 (~RST)
unnamed: R16.1, U5.18 (B0)
unnamed: R17.1, U5.17 (B1)
unnamed: R18.1, U5.16 (B2)
unnamed: R19.1, U5.15 (B3)

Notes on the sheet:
LDO 5V TO 3.3V
POWER + PROGRAMING INTERFACE
LED DRIVER
QWIIC
MOUNTING HOLE
MCU
RELAY
SCL
GND
VCC
SDA
USER I/O
I2C SENSOR +QWIIC CONNECTOR

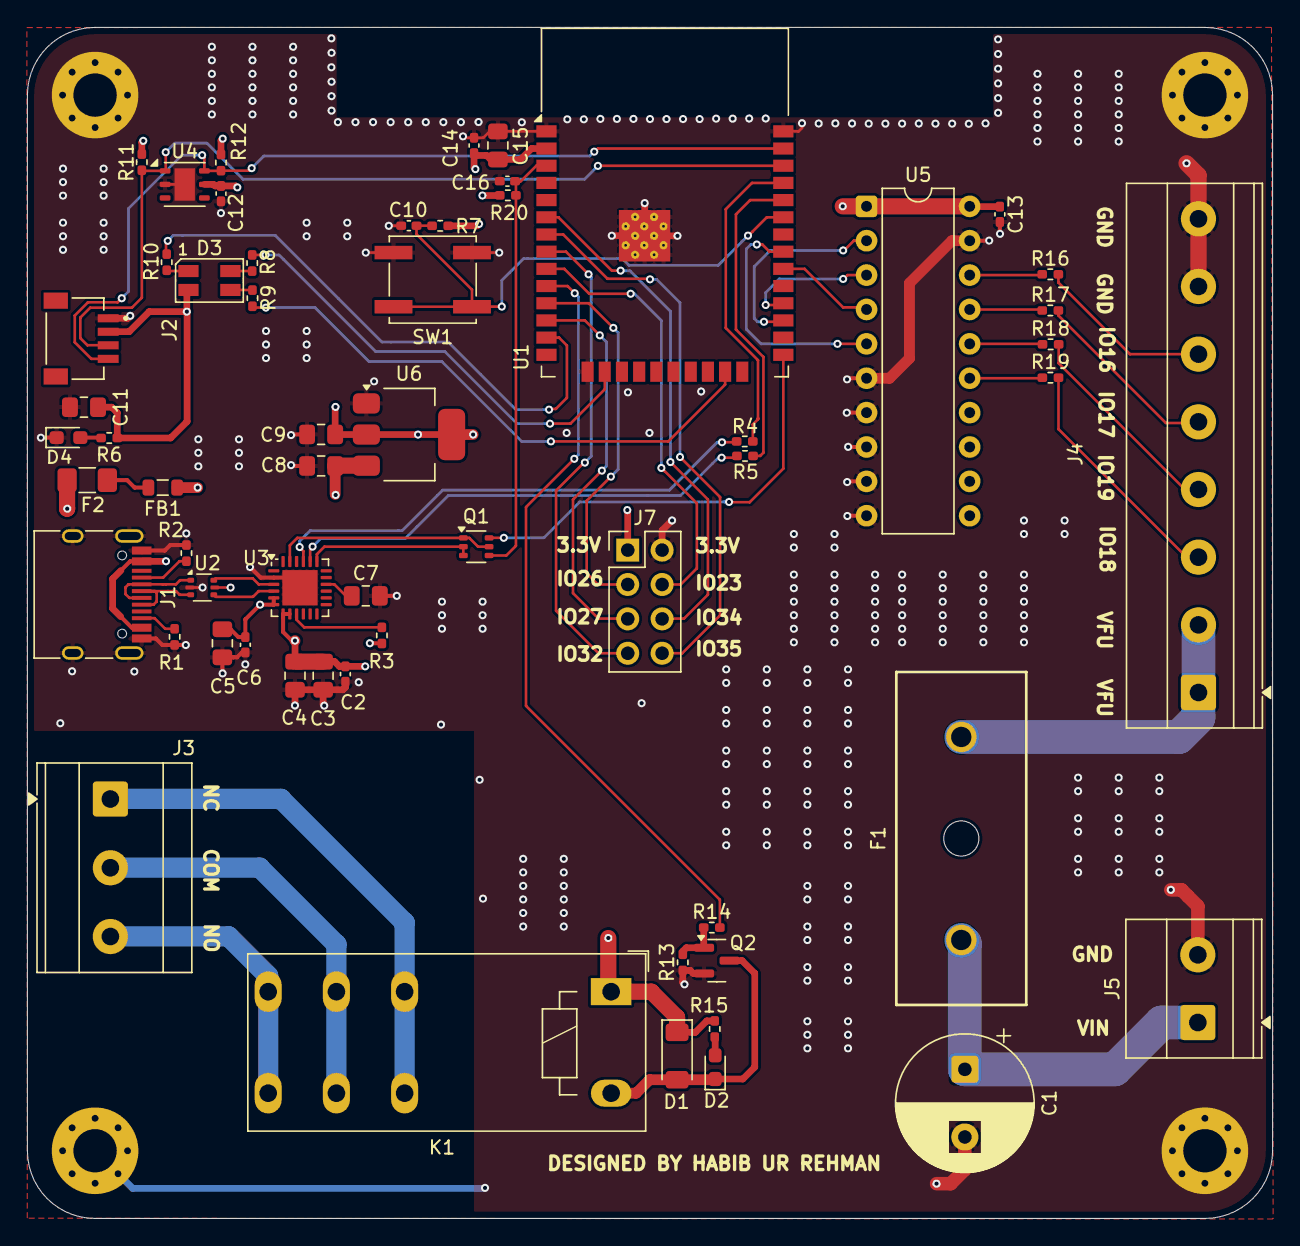
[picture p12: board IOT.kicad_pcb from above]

Board: 4 copper layers, 92.0 x 88.0 mm, 63 parts (0 on the bottom side), 58 nets.

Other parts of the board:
J7: Conn_02x04_Odd_Even; PinHeader_2x04_P2.54mm_Vertical

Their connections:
+3.3V: J7.1; also elsewhere on the board
/GPIO26: J7.3; also elsewhere on the board
/GPIO27: J7.5; also elsewhere on the board
/GPIO32: J7.7; also elsewhere on the board
/GPIO33: J7.4; also elsewhere on the board
/GPIO34: J7.6; also elsewhere on the board
/GPIO35: J7.8; also elsewhere on the board
GND: J7.2; also elsewhere on the board
